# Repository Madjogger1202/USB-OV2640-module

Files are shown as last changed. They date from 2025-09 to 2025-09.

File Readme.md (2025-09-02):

# USB-OV2640-module  

> Compact USB camera module based on **ESP32-S3** with directly soldered **OV2640** sensor (BGA footprint).  
> Conceptually close to ESP32-CAM, but implemented in a **USB stick form factor** with integrated antenna and memory.  
> Designed as a flexible platform that can later be adapted to other sensors and microcontrollers.  

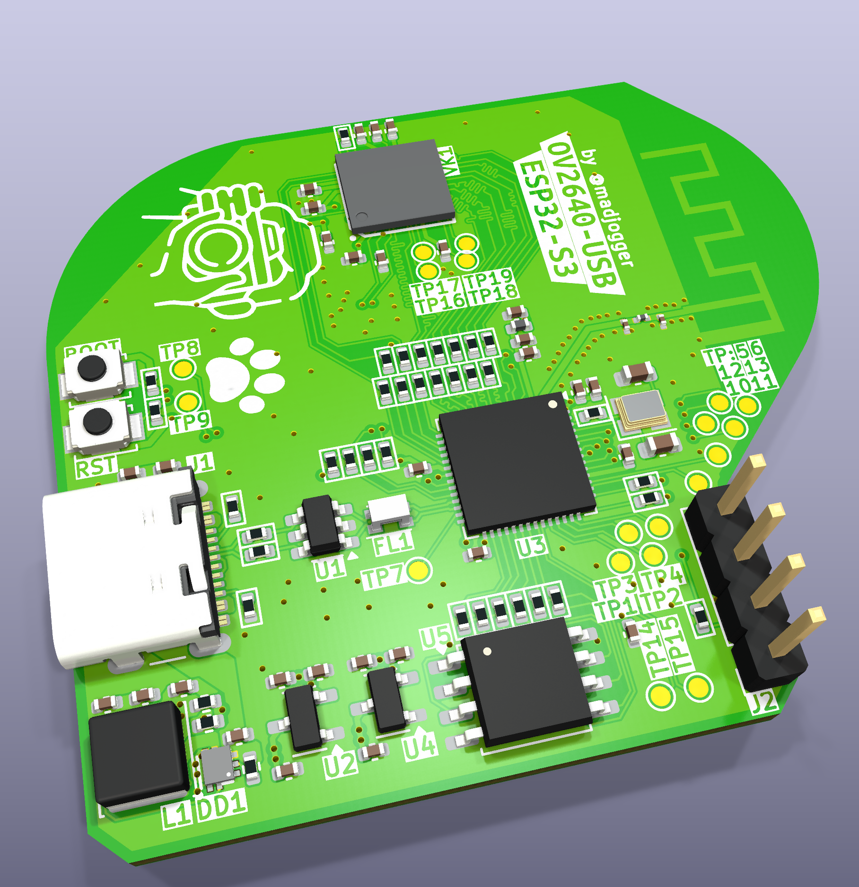
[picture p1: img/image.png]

---

## What’s on the board  
- **ESP32-S3 microcontroller**  
>  - Native **DVP camera interface** for OV2640  
>  - USB 2.0 device controller (Type-C connector)  
- **OV2640 camera sensor** in BGA package (soldered directly)  
>  - Data lines matched in length with pixel clock  
>  - Pin mapping (see table below)  
- **External memories**:  
>  - **W25Q64JVSSIQ** (SPI NOR Flash, 64 Mbit)  
>  - **LY68L6400SLIT** (PSRAM, 64 Mbit)  
- **PCB antenna**
>  - LC matching network (tunable if needed)  
- **Power & protection**:  
>  - ESD protection on USB data and power  
>  - Small differential USB filter  
- **Debug & programming**:  
>  - BOOT and RESET buttons  
>  - UART broken out for flashing/debug  
>  - Extra GPIOs exposed (see table below)  
>  - JTAG pads (MTCK, MTDO, MTDI, MTMS) 

---

## Pinout (ESP32-S3 ↔ OV2640)  

| ESP32-S3 GPIO | OV2640 Signal | Notes |
|---|---|---|
| GPIO1  | Y9 | Data bus |
| GPIO2  | Y8 | Data bus |
| GPIO3  | Y7 | Data bus |
| GPIO4  | Y6 | Data bus |
| GPIO5  | Y5 | Data bus |
| GPIO6  | Y4 | Data bus |
| GPIO7  | Y3 | Data bus |
| GPIO8  | Y2 | Data bus |
| GPIO9  | PCLK  | Pixel clock |
| GPIO10 | XVCLK | External clock |
| GPIO11 | HREF  | Horizontal reference |
| GPIO12 | VSYNC | Vertical sync |
| GPIO13 | RESETB | Sensor reset |
| GPIO18 | SIO_C | SCCB/I²C clock |
| GPIO17 | SIO_D | SCCB/I²C data |
| GPIO14 | STROBE | Camera strobe |
| GPIO38 | FREX | Frame exposure |
| GPIO37 | EXPST_B | Exposure start |

---

## Extra Exposed GPIOs  

| GPIO | Possible Functions (ESP32-S3 datasheet) |
|---|---|
| GPIO33 | ADC1_CH2 • Touch5 • RMT • SPI • UART • PWM |
| GPIO34 | ADC1_CH3 • Touch6 • RMT • SPI • UART • PWM |
| GPIO35 | ADC1_CH4 • Touch7 • RMT • SPI • UART • PWM |
| GPIO36 | ADC1_CH5 • Touch8 • RMT • SPI • UART • PWM |
| GPIO45 | General-purpose IO (no ADC/touch) • HSPI/VSPI • PWM • UART |
| GPIO46 | Input-only • Strapping pin • Can be used as input for boot mode, JTAG, etc. |
| GPIO21 | ADC2_CH0 • Touch0 • I²C SDA • UART • PWM |
| GPIO15 | ADC2_CH4 • Touch3 • I²C SCL • UART • PWM |
| GPIO16 | ADC2_CH5 • Touch4 • SPI • UART • PWM |

*Notes:*  
>- **ADC1** and **ADC2** allow analog measurements (12-bit).  
>- **TouchX** functions support capacitive touch sensing.  
>- **RMT** = Remote Control peripheral (good for IR / precise waveforms).  
>- GPIO45/46 often used in special boot/JTAG scenarios — check strapping requirements.  
>- All can be remapped to **UART / I²C / SPI / PWM** as needed (ESP32-S3 flexible IO matrix).  

---

## Power & Form Factor  
>- Powered directly from **USB Type-C**  
>- Compact **2-layer PCB** for low-cost manufacturing  
>- No external power required  

---

## Use Case  
>- Drop-in USB camera module with OV2640 sensor  
>- Alternative to ESP32-CAM with direct USB interface  
>- For prototyping, computer vision, robotics, and IoT devices  

---

## Quick Use  
>1. Connect **USB-OV2640-module** to PC via USB-C.  
>2. Hold **BOOT** and press **RESET** to enter download mode.  
>3. Flash ESP32-S3 firmware (e.g. ESP-IDF / Arduino / PlatformIO).  
>4. Use provided OV2640 driver examples (similar to ESP32-CAM).  
>5. Stream video over USB (UVC emulation) or Wi-Fi.  

---

## Notes  
>- Antenna may require LC matching calibration depending on PCB batch.  
>- OV2640 mounted directly in BGA footprint (reflow soldering required).  
>- Camera lines length-matched for stable operation at full pixel clock.  
>- PCB made as **2-layer** design for cost efficiency.  

---

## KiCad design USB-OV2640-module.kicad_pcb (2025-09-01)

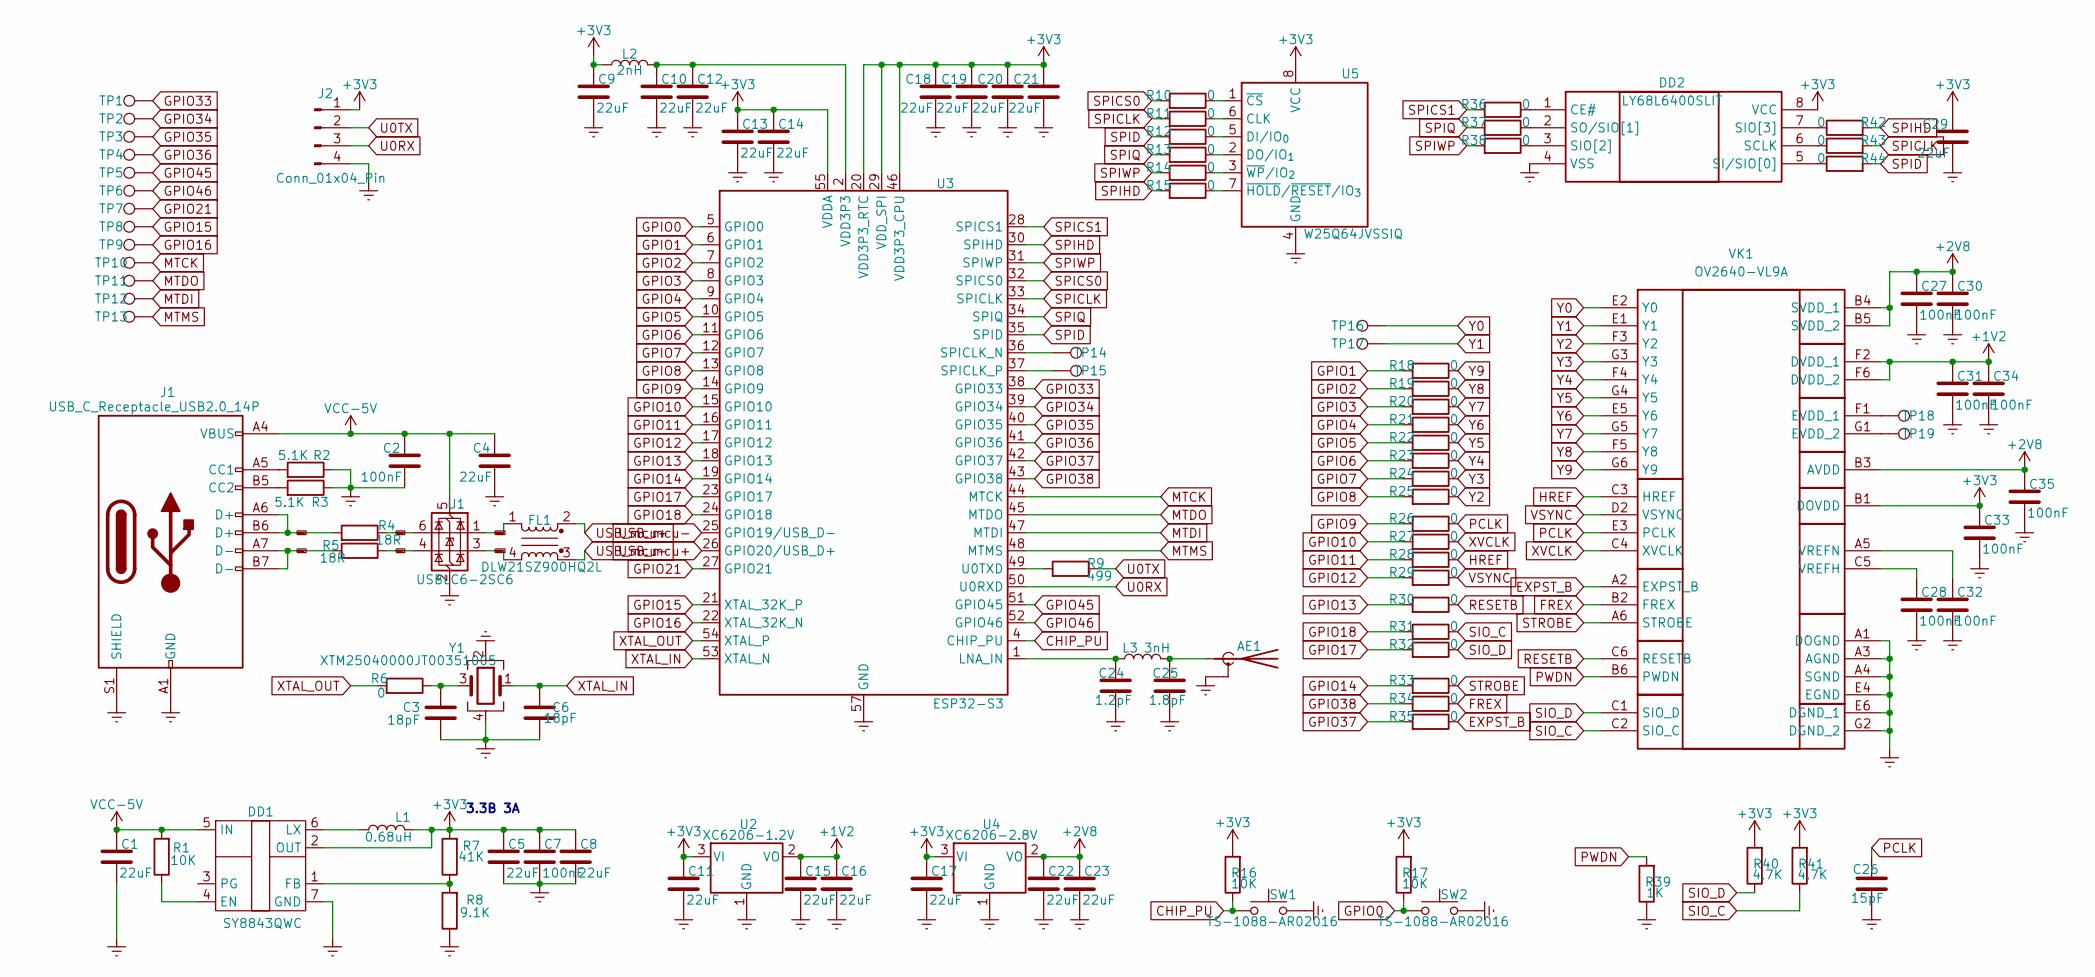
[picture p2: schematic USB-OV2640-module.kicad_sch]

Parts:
AE1: Antenna_Shield; Texas_SWRA117D_2.4GHz_Left
C1, C4, C5, C8, C9, C10, C11, C12, C13, C14, C15, C16, C17, C18, C19, C20, C21, C22, C23, C29: 22uF; C_0402_1005Metric
C2, C7, C27, C28, C30, C31, C32, C33, C34, C35: 100nF; C_0402_1005Metric
C3, C6: 18pF; C_0603_1608Metric
C24: 1.2pF; C_0201_0603Metric
C25: 1.8pF; C_0201_0603Metric
C26: 15pF; C_0402_1005Metric
DD1: SY8843QWC
DD2: LY68L6400SLIT; Manufacturer_Part_Number LY68L6400SLIT
FL1: DLW21SZ900HQ2L; L_CommonModeChoke_Coilcraft_0805USB
J1: USB_C_Receptacle_USB2.0_14P; USB_C_Receptacle_GCT_USB4105-xx-A_16P_TopMnt_Horizontal
J2: Conn_01x04_Pin; PinSocket_1x04_P2.54mm_Vertical
L1: 0.68uH; L_Cenker_CKCS4020
L2: 2nH; L_0402_1005Metric
L3: 3nH; L_0201_0603Metric
R1, R16, R17: 10K; R_0402_1005Metric
R2, R3: 5.1K; R_0402_1005Metric
R4, R5: 18R; R_0402_1005Metric
R6, R10, R11, R12, R13, R14, R15, R18, R19, R20, R21, R22, R23, R24, R25, R26, R27, R28, R29, R30, R31, R32, R33, R34, R35, R36, R37, R38, R42, R43, R44: 0; R_0402_1005Metric
R7: 41К; R_0402_1005Metric
R8: 9.1K; R_0402_1005Metric
R9: 499; R_0402_1005Metric
R39: 1K; R_0402_1005Metric
R40, R41: 4.7K; R_0402_1005Metric
SW1, SW2: TS-1088-AR02016; SW_SPST_B3U-1000P
TP1, TP2, TP3, TP4, TP5, TP6, TP7, TP8, TP9, TP10, TP11, TP12, TP13, TP14, TP15, TP16, TP17, TP18, TP19: TestPoint; TestPoint_Pad_D1.0mm
U1: USBLC6-2SC6; SOT-23-6
U2: XC6206-1.2V; SOT-23-3
U3: ESP32-S3; QFN-56-1EP_7x7mm_P0.4mm_EP4x4mm
U4: XC6206-2.8V; SOT-23-3
U5: W25Q64JVSSIQ; SOIC-8_5.3x5.3mm_P1.27mm
VK1: OV2640-VL9A; OV2640; Manufacturer_Part_Number OV2640-VL9A
Y1: XTM25040000JT00351005; Crystal_SMD_2520-4Pin_2.5x2.0mm

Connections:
+1V2: C15.1, C16.1, C31.1, C34.1, U2.2 (VO), VK1.F2 (DVDD_1), VK1.F6 (DVDD_2)
+2V8: C22.1, C23.1, C27.1, C30.1, C35.1, U4.2 (VO), VK1.B3 (AVDD), VK1.B4 (SVDD_1), VK1.B5 (SVDD_2)
+3V3: C5.1, C7.1, C8.1, C9.1, C11.1, C13.1, C14.1, C17.1, C18.1, C19.1, C20.1, C21.1, C29.1, C33.1, DD1.2 (OUT), DD2.8 (VCC), J2.1, L1.2, L2.1, R7.2, R16.2, R17.2, R40.2, R41.2, U2.3 (VI), U3.20 (VDD3P3_RTC), U3.29 (VDD_SPI), U3.46 (VDD3P3_CPU), U3.55 (VDDA), U3.56 (VDDA), U4.3 (VI), U5.8 (VCC), VK1.B1 (DOVDD)
CHIP_PU: R16.1, SW1.1, U3.4 (CHIP_PU); also elsewhere on the board
EXPST_B: R35.1, VK1.A2 (EXPST_B)
Earth: AE1.2 (Shield), C1.2, C2.2, C3.1, C4.2, C5.2, C6.1, C7.2, C8.2, C9.2, C10.2, C11.2, C12.2, C13.2, C14.2, C15.2, C16.2, C17.2, C18.2, C19.2, C20.2, C21.2, C22.2, C23.2, C24.2, C25.2, C26.2, C27.2, C28.2, C29.2, C30.2, C31.2, C32.2, C33.2, C34.2, C35.2, DD1.7 (GND), DD2.4 (VSS), J1.A1 (GND), J1.A12 (GND), J1.B1 (GND), J1.B12 (GND), J1.S1 (SHIELD), J2.4, R2.1, R3.1, R8.1, R39.1, SW1.2, SW2.2, U1.2 (GND), U2.1 (GND), U3.57 (GND), U4.1 (GND), U5.4 (GND), VK1.A1 (DOGND), VK1.A3 (AGND), VK1.A4 (SGND), VK1.E4 (EGND), VK1.E6 (DGND_1), VK1.G2 (DGND_2), Y1.2, Y1.4; also elsewhere on the board
FREX: R34.1, VK1.B2 (FREX)
GPIO0: R17.1, SW2.1, U3.5 (GPIO0); also elsewhere on the board
GPIO1: R18.2, U3.6 (GPIO1)
GPIO2: R19.2, U3.7 (GPIO2)
GPIO3: R20.2, U3.8 (GPIO3)
GPIO4: R21.2, U3.9 (GPIO4)
GPIO5: R22.2, U3.10 (GPIO5)
GPIO6: R23.2, U3.11 (GPIO6)
GPIO7: R24.2, U3.12 (GPIO7)
GPIO8: R25.2, U3.13 (GPIO8)
GPIO9: R26.2, U3.14 (GPIO9)
GPIO10: R27.2, U3.15 (GPIO10)
GPIO11: R28.2, U3.16 (GPIO11)
GPIO12: R29.2, U3.17 (GPIO12)
GPIO13: R30.2, U3.18 (GPIO13)
GPIO14: R33.2, U3.19 (GPIO14)
GPIO15: TP8.1, U3.21 (XTAL_32K_P)
GPIO16: TP9.1, U3.22 (XTAL_32K_N)
GPIO17: R32.2, U3.23 (GPIO17)
GPIO18: R31.2, U3.24 (GPIO18)
GPIO21: TP7.1, U3.27 (GPIO21)
GPIO33: TP1.1, U3.38 (GPIO33)
GPIO34: TP2.1, U3.39 (GPIO34)
GPIO35: TP3.1, U3.40 (GPIO35)
GPIO36: TP4.1, U3.41 (GPIO36)
GPIO37: R35.2, U3.42 (GPIO37)
GPIO38: R34.2, U3.43 (GPIO38)
GPIO45: TP5.1, U3.51 (GPIO45)
GPIO46: TP6.1, U3.52 (GPIO46)
HREF: R28.1, VK1.C3 (HREF)
MTCK: TP10.1, U3.44 (MTCK)
MTDI: TP12.1, U3.47 (MTDI)
MTDO: TP11.1, U3.45 (MTDO)
MTMS: TP13.1, U3.48 (MTMS)
unnamed: AE1.1 (A), C25.1, L3.2
unnamed: C3.2, R6.1, Y1.3
unnamed: C10.1, C12.1, L2.2, U3.2 (VDD3P3), U3.3 (VDD3P3)
unnamed: DD1.4 (EN), R1.1
unnamed: DD1.1 (FB), R7.1, R8.2
unnamed: DD1.6 (LX), L1.1
unnamed: DD2.1 (CE#), R36.1
unnamed: DD2.6 (SCLK), R43.1
unnamed: DD2.3 (SIO[2]), R38.1
unnamed: DD2.7 (SIO[3]), R42.1
unnamed: DD2.5 (SI/SIO[0]), R44.1
unnamed: DD2.2 (SO/SIO[1]), R37.1
unnamed: J1.A5 (CC1), R2.2
unnamed: J1.B5 (CC2), R3.2
unnamed: C24.1, L3.1, U3.1 (LNA_IN)
unnamed: TP14.1, U3.36 (SPICLK_N)
unnamed: TP15.1, U3.37 (SPICLK_P)
unnamed: R9.2, U3.49 (U0TXD)
unnamed: R11.1, U5.6 (CLK)
unnamed: R12.1, U5.5 (DI/IO_{0})
unnamed: R13.1, U5.2 (DO/IO_{1})
unnamed: R10.1, U5.1 (~CS)
unnamed: R15.1, U5.7 (~HOLD/~RESET/IO_{3})
unnamed: R14.1, U5.3 (~WP/IO_{2})
unnamed: TP18.1, VK1.F1 (EVDD_1)
unnamed: TP19.1, VK1.G1 (EVDD_2)
unnamed: C28.1, VK1.C5 (VREFH)
unnamed: C32.1, VK1.A5 (VREFN)
PCLK: C26.1, R26.1, VK1.E3 (PCLK)
PWDN: R39.2, VK1.B6 (PWDN)
RESETB: R30.1, VK1.C6 (RESETB)
SIO_C: R31.1, R41.1, VK1.C2 (SIO_C)
SIO_D: R32.1, R40.1, VK1.C1 (SIO_D)
SPICLK: R11.2, R43.2, U3.33 (SPICLK)
SPICS0: R10.2, U3.32 (SPICS0)
SPICS1: R36.2, U3.28 (SPICS1)
SPID: R12.2, R44.2, U3.35 (SPID)
SPIHD: R15.2, R42.2, U3.30 (SPIHD)
SPIQ: R13.2, R37.2, U3.34 (SPIQ)
SPIWP: R14.2, R38.2, U3.31 (SPIWP)
STROBE: R33.1, VK1.A6 (STROBE)
U0RX: J2.3, U3.50 (U0RXD)
U0TX: J2.2, R9.1
USB_con+: J1.A6 (D+), J1.B6 (D+), R4.2
USB_con-: J1.A7 (D-), J1.B7 (D-), R5.2
USB_filter+: FL1.1, U1.1 (I/O1)
USB_filter-: FL1.4, U1.3 (I/O2)
USB_mcu+: FL1.2, U3.26 (GPIO20/USB_D+)
USB_mcu-: FL1.3, U3.25 (GPIO19/USB_D-)
USB_res+: R4.1, U1.6 (I/O1)
USB_res-: R5.1, U1.4 (I/O2)
VCC-5V: C1.1, C2.1, C4.1, DD1.5 (IN), J1.A4 (VBUS), J1.A9 (VBUS), J1.B4 (VBUS), J1.B9 (VBUS), R1.2, U1.5 (VBUS)
VSYNC: R29.1, VK1.D2 (VSYNC)
XTAL_IN: C6.2, U3.53 (XTAL_N), Y1.1
XTAL_OUT: R6.2, U3.54 (XTAL_P)
XVCLK: R27.1, VK1.C4 (XVCLK)
Y0: TP16.1, VK1.E2 (Y0)
Y1: TP17.1, VK1.E1 (Y1)
Y2: R25.1, VK1.F3 (Y2)
Y3: R24.1, VK1.G3 (Y3)
Y4: R23.1, VK1.F4 (Y4)
Y5: R22.1, VK1.G4 (Y5)
Y6: R21.1, VK1.E5 (Y6)
Y7: R20.1, VK1.G5 (Y7)
Y8: R19.1, VK1.F5 (Y8)
Y9: R18.1, VK1.G6 (Y9)

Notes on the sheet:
3.3В 3А

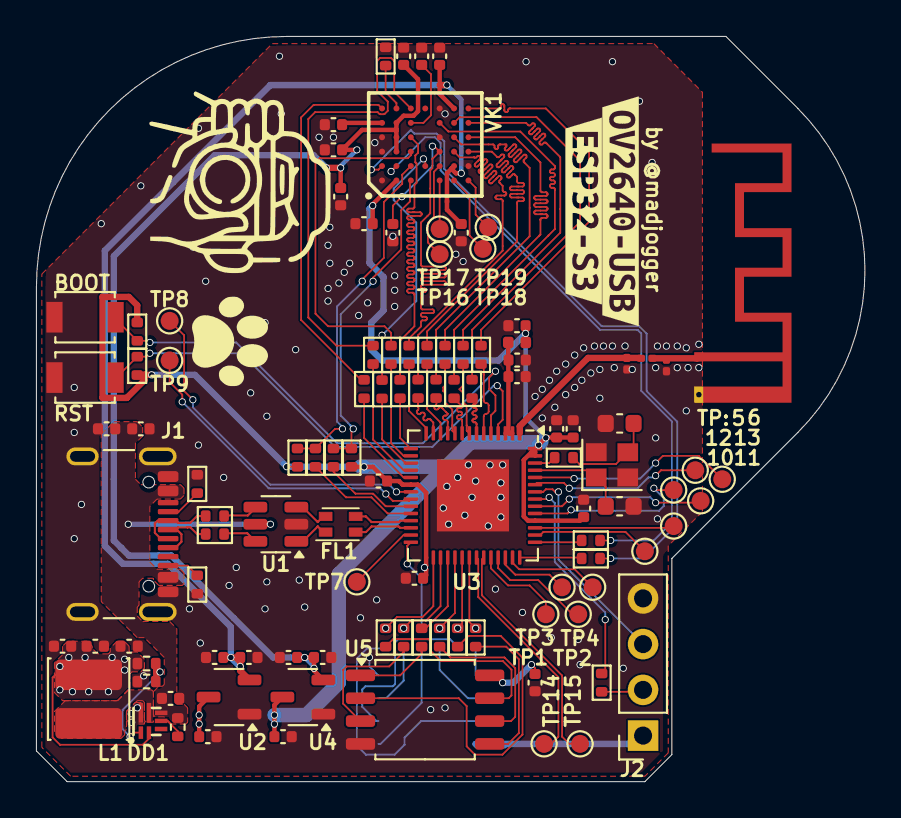
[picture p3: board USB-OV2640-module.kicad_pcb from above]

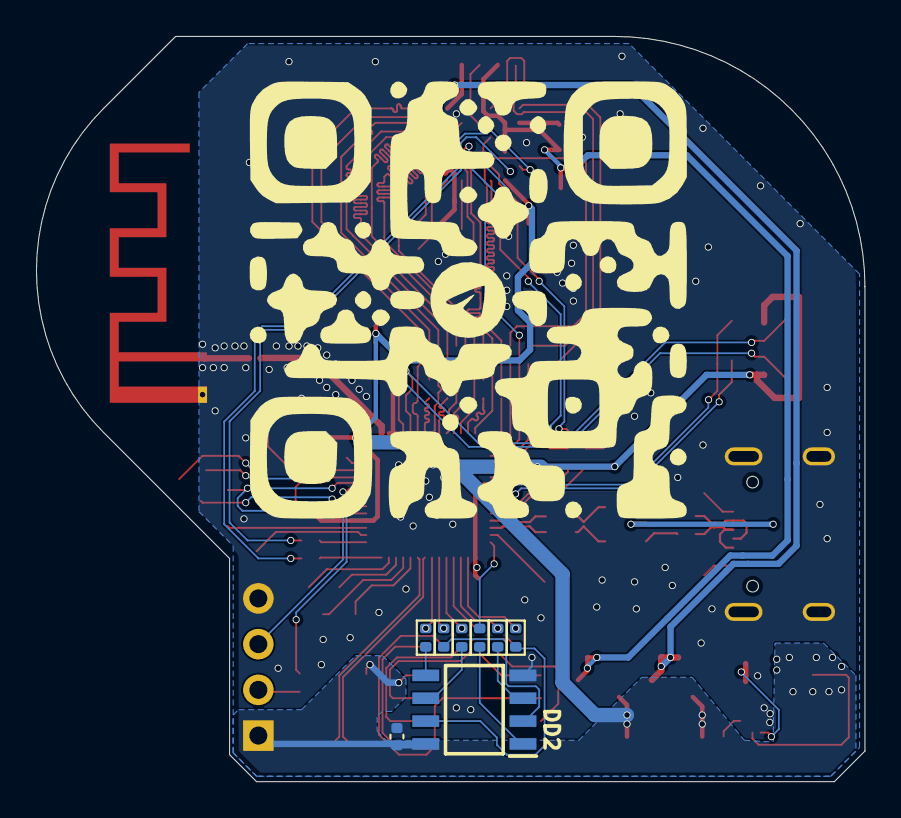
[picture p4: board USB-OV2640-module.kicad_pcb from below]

Board: 2 copper layers, 46.0 x 41.4 mm, 118 parts (8 on the bottom side), 106 nets.

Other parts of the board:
BOOT: TS-1088-AR02016; SW_SPST_B3U-1000P
RST: TS-1088-AR02016; SW_SPST_B3U-1000P
kibuzzard-68B606AE: G***; kibuzzard-68B606AE
kibuzzard-68B606C1: G***; kibuzzard-68B606C1

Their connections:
CHIP_PU: RST.1; also elsewhere on the board
Earth: BOOT.2, RST.2; also elsewhere on the board
GPIO0: BOOT.1; also elsewhere on the board

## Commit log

2025-08-31 schematics done
    [USB-OV2640-module.kicad_pcb, USB-OV2640-module.kicad_sch]
2025-09-01 Rev0 ready
    [USB-OV2640-module.kicad_pcb, USB-OV2640-module.kicad_sch]
